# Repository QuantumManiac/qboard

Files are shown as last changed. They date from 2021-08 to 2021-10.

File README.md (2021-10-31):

# QBoard
A custom (almost) full-size mechanical keyboard with a detachable numpad

## Pictures
Keyboard PCB
Keyboard Picture

## BOM
A BOM of parts used can be found [here](https://github.com/QuantumManiac/qboard/tree/main/bom)

## Firmware
Rough notes for configuring the MCU and flashing firmware can be found [here](https://github.com/QuantumManiac/qboard/tree/main/qmk_firmware)

## Improvements
- Improving on the numpad connector - don't fit well and when connected isn't sturdy
- Switching out direct soldering of keyswitches onto PCB with hot-swap sockets

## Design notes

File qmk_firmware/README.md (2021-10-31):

# Firmware Notes
Below are some rough notes that I wrote as I was figuring out how to get the various configurations and USB bootloader onto the MCU with my Raspberry Pi.

[USBaspLoader and QMK on ATmega328P · GitHub](https://gist.github.com/nullstalgia/e5a010c50061e54cbc88b9ea4e2468e2)

## Connecting AVRDude on RasPi to ATMega

Instructions: [How to Program an AVR/Arduino using the Raspberry Pi GPIO](https://ozzmaker.com/program-avr-using-raspberry-pi-gpio/)

- When install avrdude, DO NOT IGNORE the warnings that `libusb`, `libftdi` not installed, need to install
- Note - this is for an arduino. Use this MCU's pinout and `-p` flag (for avrdude)
  - `-p` flag (use `-p m32`): [AVRDUDE: 2.1 Option Descriptions](https://www.nongnu.org/avrdude/user-manual/avrdude_4.html)
  - ATMega32 Datasheet: [ATmega32/L Datasheet](https://www.mouser.ca/datasheet/2/268/doc2503-1315184.pdf)
  - RasPi 3B Rev 1 pinout: [Pin Numbering - Raspberry Pi 3 Model B](https://pi4j.com/1.2/pins/model-3b-rev1.html)

## Setting Fuses

Fuse Calculator: [AVR® Fuse Calculator – The Engbedded Blog](https://www.engbedded.com/fusecalc/)

Fuse Flashing Instructions: [Mechanical Keyboard Prototype With V-USB & QMK](https://www.ghost7.com/mechanical-keyboard-prototype-with-v-usb-qmk/)

- Setting fuses to use external xtal and disable brownout protection
- Don't forget to hook up xtal as described (22pF caps w/ 16MHz xtal)
- Use ATMega32A settings for avrdude
  - `sudo avrdude -c linuxgpio -p m32 -v -u -U lfuse:w:0x1F:m -U hfuse:w:0xC0:m`

## Flashing USBaspLoader

See first section of: [USBaspLoader and QMK on ATmega328P · GitHub](https://gist.github.com/nullstalgia/e5a010c50061e54cbc88b9ea4e2468e2)

Also see relevant section of: [Mechanical Keyboard Prototype With V-USB & QMK](https://www.ghost7.com/mechanical-keyboard-prototype-with-v-usb-qmk/)

- In `Makefile.inc` for USBaspLoader, set gpio as programmer
  - `PROGRAMMER = -c linuxgpio`
- Make following changes to `bootloaderconfig.h`
  - `#define USB\_CFG\_INTPORT\_BIT 2`
  - `#define USB\_CFG\_DMINUS\_BIT 3`
  - `#define JUMPER\_BIT 6`

- Flash USBAspLoader

## Flash QMK

Guide on flashing the firmware: [QMK Firmware](https://docs.qmk.fm/#/hand_wire)

USB Driver Installer: [https://zadig.akeo.ie/](https://zadig.akeo.ie/)

- Short PD6 to GND (Or hold BOOT key) for programming mode when flashing firmware
- plug into PC w/ via USB
- May need to use to install libusbK if flashing doesn't work

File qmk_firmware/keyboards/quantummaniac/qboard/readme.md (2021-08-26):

# qboard

qboard

*A short description of the keyboard/project*

* Keyboard Maintainer: [QuantumManiac](https://github.com/QuantumManiac)
* Hardware Supported: *The PCBs, controllers supported*
* Hardware Availability: *Links to where you can find this hardware*

Make example for this keyboard (after setting up your build environment):

    make qboard:default

Flashing example for this keyboard:

    make qboard:default:flash

See the [build environment setup](https://docs.qmk.fm/#/getting_started_build_tools) and the [make instructions](https://docs.qmk.fm/#/getting_started_make_guide) for more information. Brand new to QMK? Start with our [Complete Newbs Guide](https://docs.qmk.fm/#/newbs).

## Bootloader

Enter the bootloader in 3 ways:

* **Bootmagic reset**: Hold down the key at (0,0) in the matrix (usually the top left key or Escape) and plug in the keyboard
* **Physical reset button**: Briefly press the button on the back of the PCB - some may have pads you must short instead
* **Keycode in layout**: Press the key mapped to `RESET` if it is available

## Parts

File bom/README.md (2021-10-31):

# Bill of Materials
|Name |Description |Qty|Link |Comments |
|---|---|---|---|---|
|CHERRY MX 3 PIN SWITCHES - BLUE |Keyswitches |101|[Link](https://kbdfans.com/collections/cherry-switches/products/cherry-mx-swtich?variant=36019543757) |Replace with 3-pin MX switches of choice |
|3mm LEDs - 2 Pin |Keyswitch and Indicator LEDs |105|[Link](https://www.amazon.ca/DiCUNO-1000pcs-Emitting-Diffused-Assorted/dp/B07KGQMGY7) |Pick color of choice. Ensure 3mm and preferably flange-less |
|ATMEGA32-16PU |Microcontroller |1  |[Link](https://www.mouser.ca/ProductDetail/Microchip-Technology-Atmel/ATMEGA32-16PU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) | |
|TZX3V6A-TR |Zener Diodes - 3.6V |2  |[Link](https://www.mouser.ca/ProductDetail/Vishay-Semiconductors/TZX3V6A-TR?qs=oNDV51lhjENtvfdCBFOJTw%3D%3D) |For USB-C |
|MF-R050 |Resettable Fuse - 500mA |1  |[Link](https://www.mouser.ca/ProductDetail/Bourns/MF-R050?qs=A6omU7D3gEWzJRzbTsuTwA%3D%3D) | |
|MJTP1230A |Pushbutton Switch |2  |[Link](https://www.mouser.ca/ProductDetail/Apem/MJTP1230A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) |For BOOT and RESET switches |
|ABL-16.000MHz-B4Y |Crystal - 16MHz |1  |[Link](https://www.mouser.ca/ProductDetail/ABRACON/ABL-16000MHz-B4Y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) |MCU Clock |
|1N4148TR |Diodes - Ultra-fast, 100V, 0.3A|102|[Link](https://www.mouser.ca/ProductDetail/onsemi-Fairchild/1N4148TR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) |Diodes for keys |
|10k R |Resistors |2  |[Link](https://www.mouser.ca/ProductDetail/YAGEO/MFR-12FRF52-10K?qs=19cKSROHwrBLAZVjkXsohw%3D%3D) | |
|1.5k R |Resistors |5  |[Link](https://www.mouser.ca/ProductDetail/YAGEO/MFR-12FTF52-1K5?qs=oAGoVhmvjhypP%2FVrWmgF1g%3D%3D) | |
|5.1k R |Resistors |2  |[Link](https://www.mouser.ca/ProductDetail/YAGEO/MFR-12FTF52-5K1?qs=oAGoVhmvjhy1wGcoKYGIuA%3D%3D) | |
|75 R |Resistors |2  |[Link](https://www.mouser.ca/ProductDetail/YAGEO/CFR-12JR-52-75R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) | |
|470 R |Resistors |102|[Link](https://www.mouser.ca/ProductDetail/YAGEO/CFR-12JT-52-470R?qs=sGAEpiMZZMtG0KNrPCHnjXb9qW87MP8uBQR6Le236lY%3D) | |
|22p C |Capacitors |2  |[Link](https://www.mouser.ca/ProductDetail/Murata-Electronics/RCE5C2A220J0A2H03B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) | |
|4.7u C (Polarized) |Capacitors |1  |[Link](https://www.mouser.ca/ProductDetail/Nichicon/UMT1H4R7MDD1TP?qs=Q7H%2Fb6Evq9zwCrKrvu5SEQ%3D%3D) | |
|0.1u C |Capacitors |2  |[Link](https://www.mouser.ca/ProductDetail/Murata-Electronics/RDER71H104K0M1H03A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) | |
|ORIGINAL CHERRY PCB-MOUNT STABILIZERS|Key Stabilizers |1  |[Link](https://kbdfans.com/products/cherry-original-pcb-stabilizers?variant=39444796997771) |Need 4x 2U, 2x 2.25U, 1x 6.25U |
|571-1-2199299-5 |IC Socket - 40-Pin |1  |[Link](https://www.digikey.ca/en/products/detail/te-connectivity-amp-connectors/1-2199299-5/5022052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) | |
|640-USB4085-GF-A |Through-hole USB-C Connector |1  |[Link](https://www.digikey.ca/en/products/detail/gct/USB4085-GF-A/9859662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) | |
|726-IPI45N06S409AKSA |MOSFET NPN Transistor |1  |[Link](https://www.digikey.ca/en/products/detail/IPP060N06NAKSA1/IPP060N06NAKSA1-ND/3687558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)|For LED Backlighting |
|SBH11-PBPC-D08-RA-BK |2x7 connector (Male) |1  |[Link](https://www.digikey.ca/en/products/detail/sullins-connector-solutions/SBH11-PBPC-D08-RA-BK/1990072) |For connecting numpad. The male and female connector DO NOT pair up well. Suggest finding alternative |
|PPPC082LJBN-RC |2x7 connector (Female) |1  |[Link](https://www.digikey.ca/en/products/detail/sullins-connector-solutions/PPPC082LJBN-RC/776019) |For connecting numpad. The male and female connector DO NOT pair up well. Suggest finding alternative |
|571-2842126-3 |3x2 Pin Header |1  |[Link](https://www.digikey.ca/en/products/detail/amphenol-icc-fci/10129381-906001BLF/7916070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) |ISP Header for programming the MCU |
|Adhesive-Back Bumpers - 95495K15 |Grippy Feet |8  |[Link](https://www.mcmaster.com/catalog/127/4126) |Feet for keyboard |
|611-PTS645VH392 |Horizontal Pushbutton Switch |1  |[Link](https://www.digikey.ca/en/products/detail/c-k/PTS645VH39-2-LFS/1146767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) |Switch for adjusting backlight |
|M2 Standoff Assorted Kit |Standoffs |1  |[Link](https://www.amazon.ca/Litorange-320PCS-Standoff-Assorted-Assortment/dp/B07D78PFQL) |Used 10mm between base plate and PCB. 15mm between PCB and clear cover. Use male-female on one standoff when going base plate -> PCB -> cover, else use female-female|
|M2 Screws |Screws |?  |N/A | |
|3mm Acrylic - Clear |Acrylic |1  |N/A |Use "_cover_acrylic_clear" file for cuts |
|3mm Acrylic - Black |Acrylic |1  |N/A |Use "_plate_acrylic_black" file for cuts |
|PCB - Black |PCBs |1  |[Link](https://jlcpcb.com/) |One of each "main" and "numpad" |

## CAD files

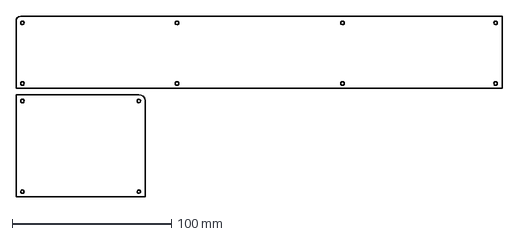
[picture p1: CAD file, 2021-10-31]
acrylic/_cover_acrylic_clear.dxf
304.8 x 112.9 mm

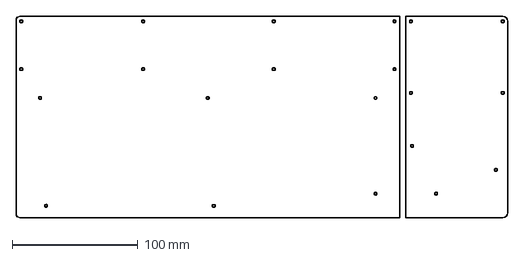
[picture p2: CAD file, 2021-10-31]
acrylic/_plate_acrylic_black.dxf
390.9 x 160.2 mm

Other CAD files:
acrylic/main_plate.dwg
acrylic/numpad_plate.dwg
acrylic/_cover_acrylic_clear.dwg
acrylic/_plate_acrylic_black.dwg

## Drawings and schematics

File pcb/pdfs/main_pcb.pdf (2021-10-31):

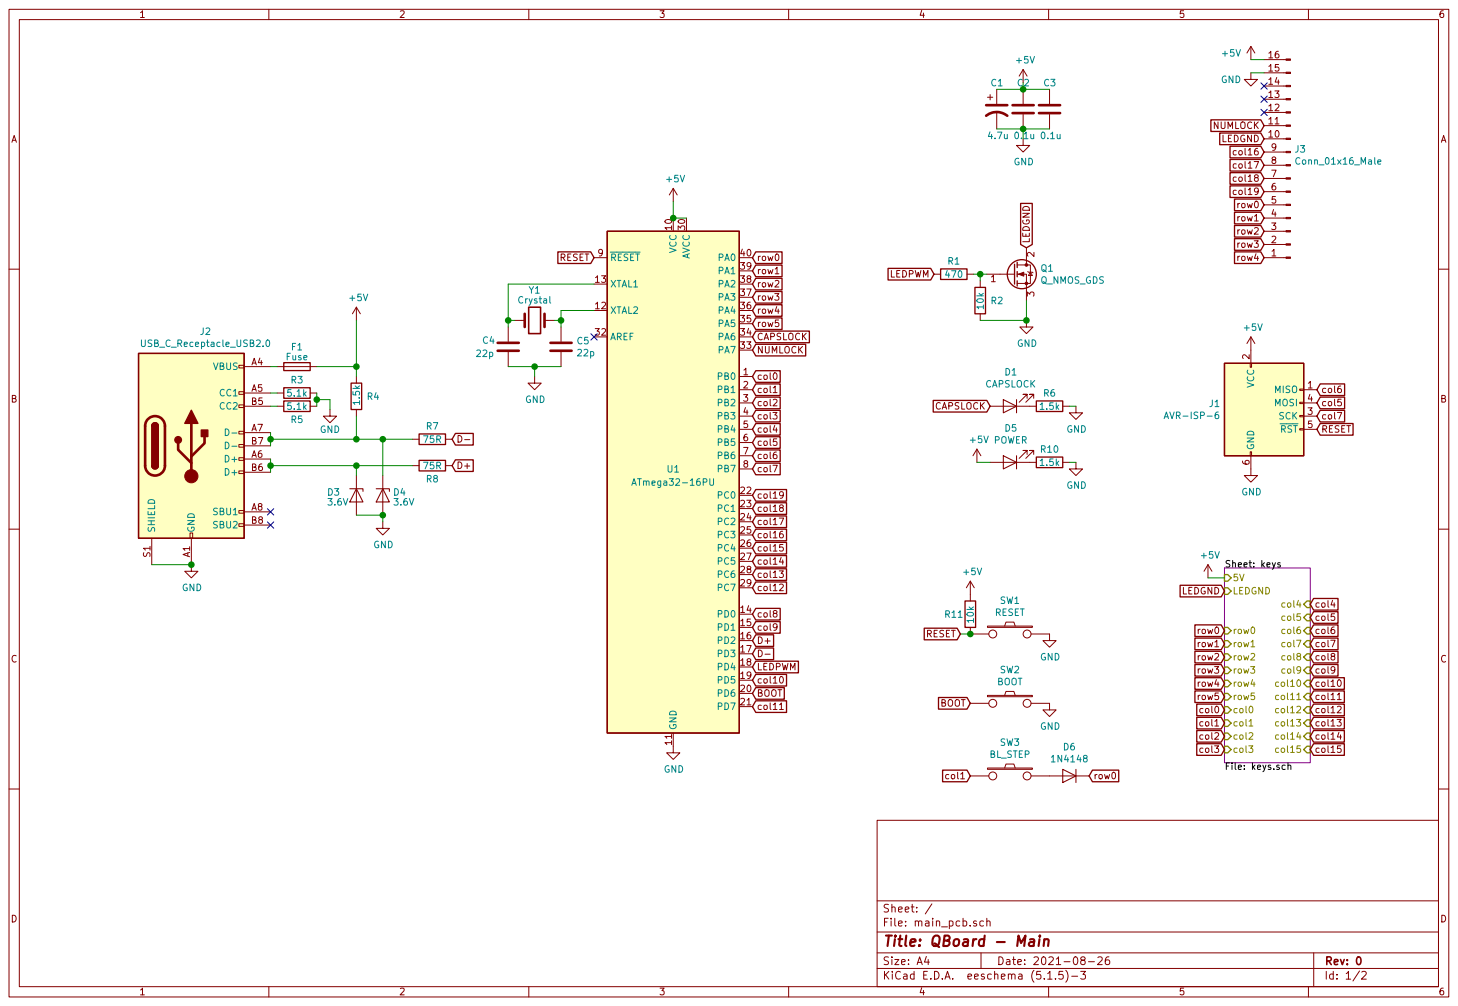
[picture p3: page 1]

Id: 1/2 Title: QBoard - Main

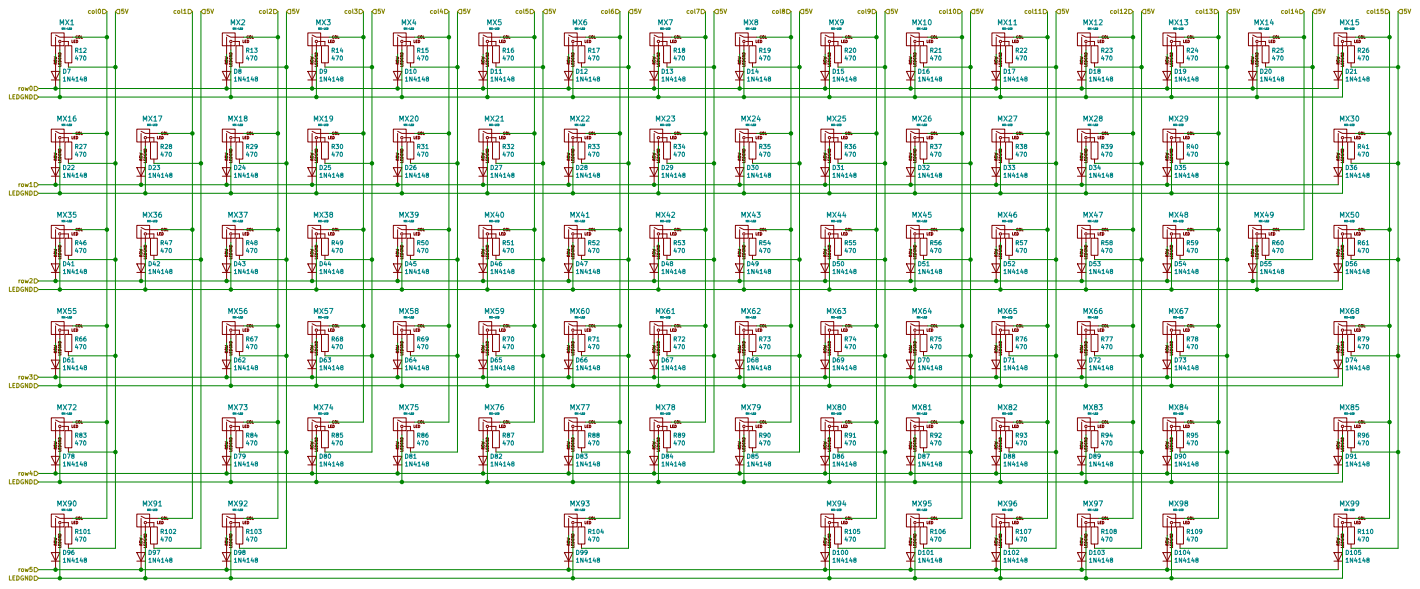
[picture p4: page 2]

Sheet: /keys/
File: keys.sch
Id: 2/2 Title: QBoard - Main Keys

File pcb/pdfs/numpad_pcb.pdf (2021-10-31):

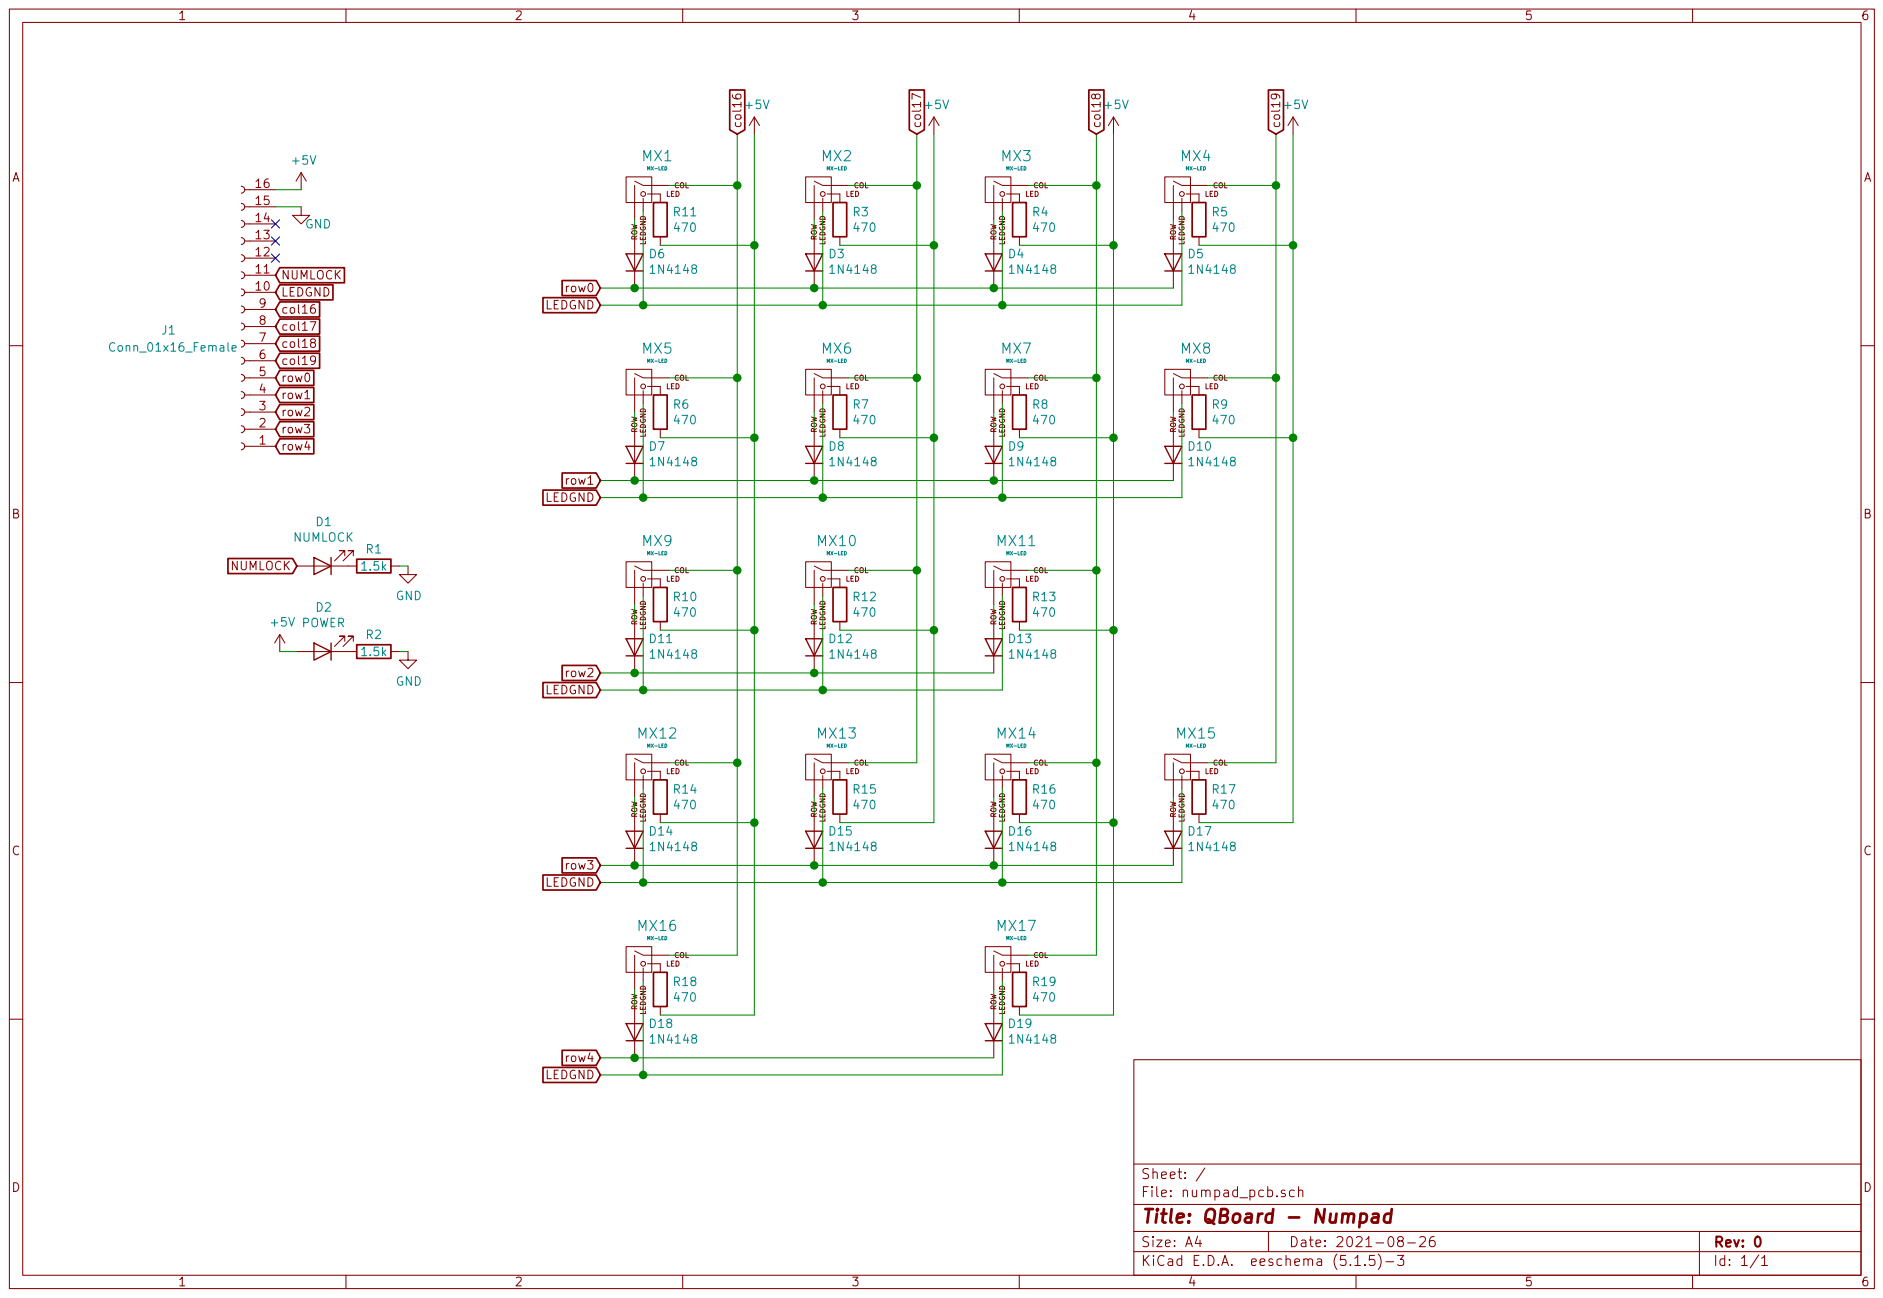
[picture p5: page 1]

File: numpad_pcb.sch Sheet: /
Id: 1/1 Title: QBoard - Numpad

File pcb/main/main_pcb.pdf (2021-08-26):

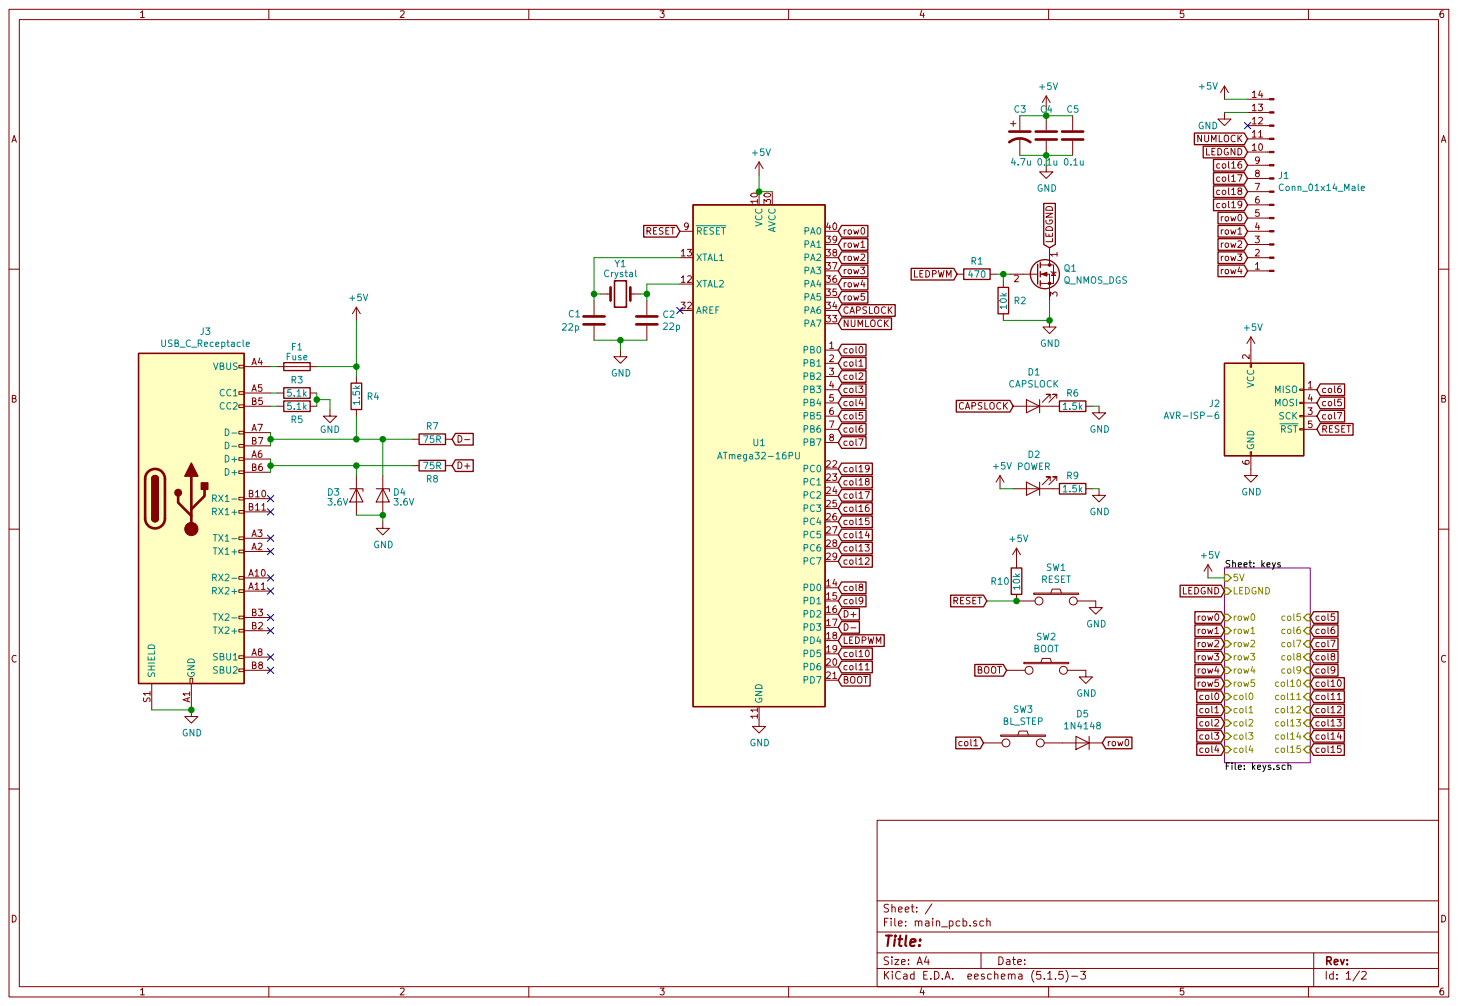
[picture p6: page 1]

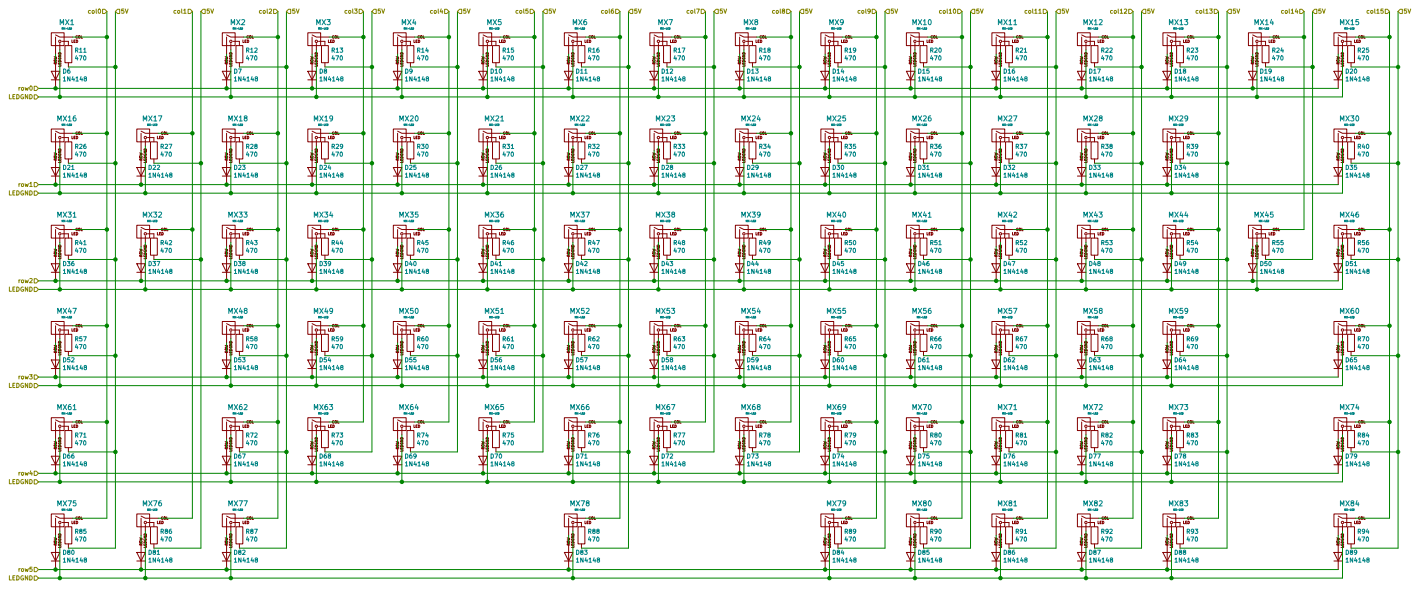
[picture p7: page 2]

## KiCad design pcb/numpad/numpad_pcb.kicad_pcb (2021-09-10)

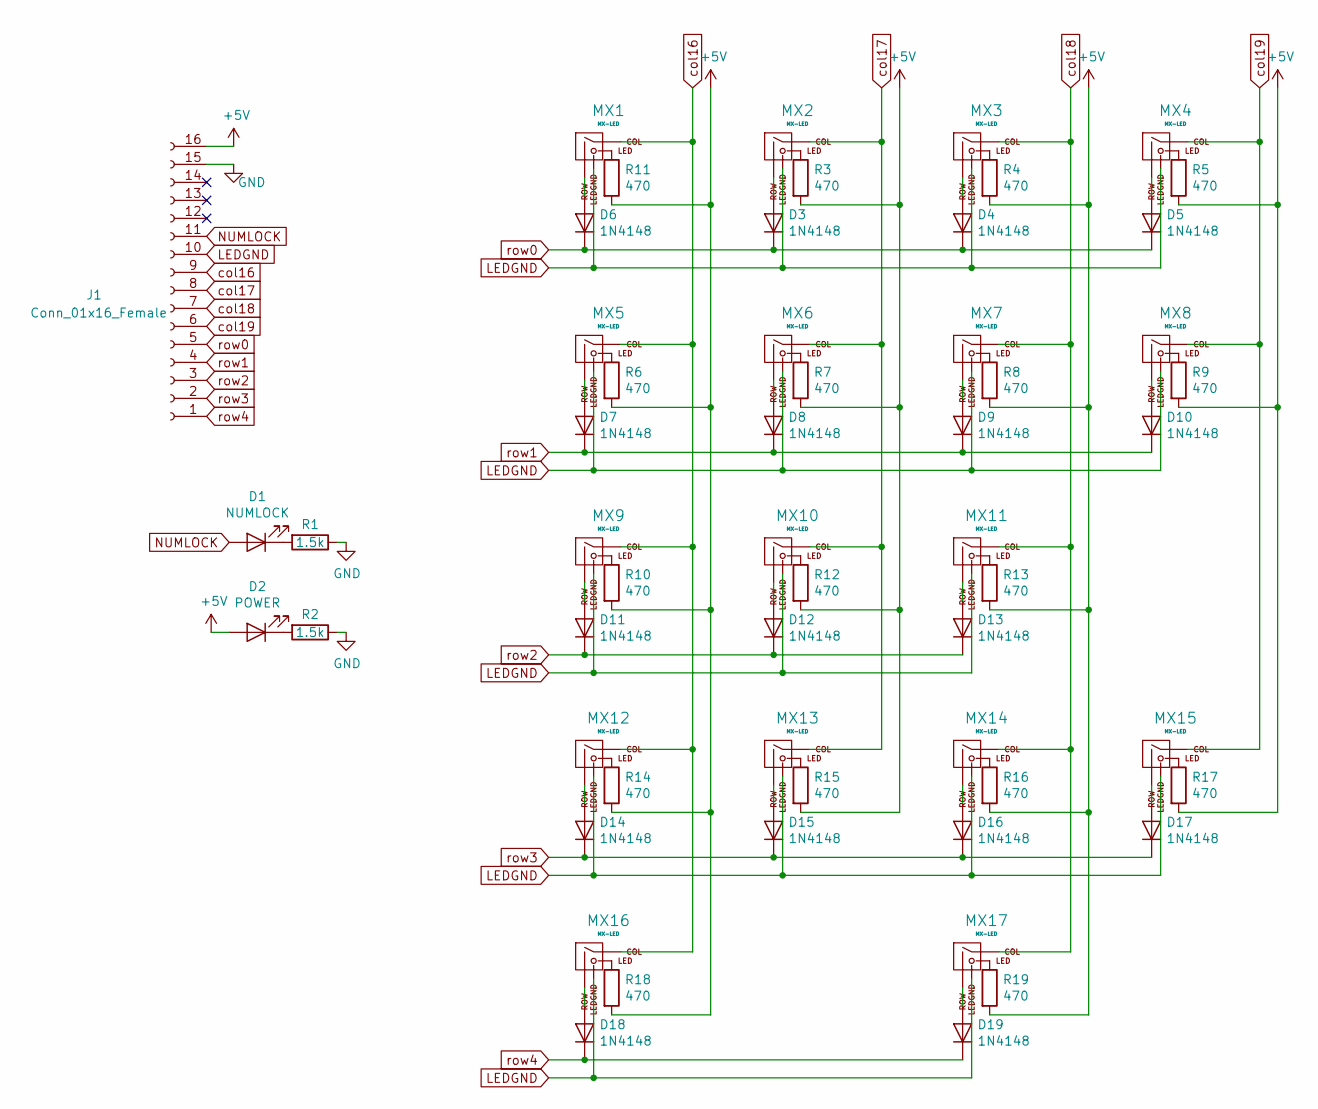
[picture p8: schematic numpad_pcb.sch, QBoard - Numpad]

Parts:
D1: NUMLOCK; LED_D3.0mm_Clear
D2: POWER; LED_D3.0mm_Clear
D3, D4, D5, D6, D7, D8, D9, D10, D11, D12, D13, D14, D15, D16, D17, D18, D19: 1N4148; D_DO-35_SOD27_P7.62mm_Horizontal
J1: Conn_01x16_Female; PinSocket_2x08_P2.54mm_Horizontal
MX1, MX2, MX3, MX4, MX5, MX6, MX7, MX9, MX10, MX11, MX12, MX13, MX14, MX17: MX-LED; MXOnly-1U
MX8, MX15: MX-LED; MXOnly-2U-ReversedVerticalStabilizers
MX16: MX-LED; MXOnly-2U-FLIPPED-ReversedStabilizers
R1, R2: 1.5k; R_Axial_DIN0204_L3.6mm_D1.6mm_P7.62mm_Horizontal
R3, R4, R5, R6, R7, R8, R9, R10, R11, R12, R13, R14, R15, R16, R17, R18, R19: 470; R_Axial_DIN0204_L3.6mm_D1.6mm_P7.62mm_Horizontal

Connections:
+5V: D2.2 (A), J1.16, R3.2, R4.2, R5.2, R6.2, R7.2, R8.2, R9.2, R10.2, R11.2, R12.2, R13.2, R14.2, R15.2, R16.2, R17.2, R18.2, R19.2
GND: J1.15, R1.1, R2.1
LEDGND: J1.10, MX1.4 (LEDGND), MX2.4 (LEDGND), MX3.4 (LEDGND), MX4.4 (LEDGND), MX5.4 (LEDGND), MX6.4 (LEDGND), MX7.4 (LEDGND), MX8.4 (LEDGND), MX9.4 (LEDGND), MX10.4 (LEDGND), MX11.4 (LEDGND), MX12.4 (LEDGND), MX13.4 (LEDGND), MX14.4 (LEDGND), MX15.4 (LEDGND), MX16.4 (LEDGND), MX17.4 (LEDGND)
NUMLOCK: D1.2 (A), J1.11
unnamed: D1.1 (K), R1.2
unnamed: D2.1 (K), R2.2
unnamed: D3.2 (A), MX2.2 (ROW)
unnamed: D4.2 (A), MX3.2 (ROW)
unnamed: D5.2 (A), MX4.2 (ROW)
unnamed: D6.2 (A), MX1.2 (ROW)
unnamed: D7.2 (A), MX5.2 (ROW)
unnamed: D8.2 (A), MX6.2 (ROW)
unnamed: D9.2 (A), MX7.2 (ROW)
unnamed: D10.2 (A), MX8.2 (ROW)
unnamed: D11.2 (A), MX9.2 (ROW)
unnamed: D12.2 (A), MX10.2 (ROW)
unnamed: D13.2 (A), MX11.2 (ROW)
unnamed: D14.2 (A), MX12.2 (ROW)
unnamed: D15.2 (A), MX13.2 (ROW)
unnamed: D16.2 (A), MX14.2 (ROW)
unnamed: D17.2 (A), MX15.2 (ROW)
unnamed: D18.2 (A), MX16.2 (ROW)
unnamed: D19.2 (A), MX17.2 (ROW)
unnamed: MX1.3 (LED), R11.1
unnamed: MX2.3 (LED), R3.1
unnamed: MX3.3 (LED), R4.1
unnamed: MX4.3 (LED), R5.1
unnamed: MX5.3 (LED), R6.1
unnamed: MX6.3 (LED), R7.1
unnamed: MX7.3 (LED), R8.1
unnamed: MX8.3 (LED), R9.1
unnamed: MX9.3 (LED), R10.1
unnamed: MX10.3 (LED), R12.1
unnamed: MX11.3 (LED), R13.1
unnamed: MX12.3 (LED), R14.1
unnamed: MX13.3 (LED), R15.1
unnamed: MX14.3 (LED), R16.1
unnamed: MX15.3 (LED), R17.1
unnamed: MX16.3 (LED), R18.1
unnamed: MX17.3 (LED), R19.1
col16: J1.9, MX1.1 (COL), MX5.1 (COL), MX9.1 (COL), MX12.1 (COL), MX16.1 (COL)
col17: J1.8, MX2.1 (COL), MX6.1 (COL), MX10.1 (COL), MX13.1 (COL)
col18: J1.7, MX3.1 (COL), MX7.1 (COL), MX11.1 (COL), MX14.1 (COL), MX17.1 (COL)
col19: J1.6, MX4.1 (COL), MX8.1 (COL), MX15.1 (COL)
row0: D3.1 (K), D4.1 (K), D5.1 (K), D6.1 (K), J1.5
row1: D7.1 (K), D8.1 (K), D9.1 (K), D10.1 (K), J1.4
row2: D11.1 (K), D12.1 (K), D13.1 (K), J1.3
row3: D14.1 (K), D15.1 (K), D16.1 (K), D17.1 (K), J1.2
row4: D18.1 (K), D19.1 (K), J1.1

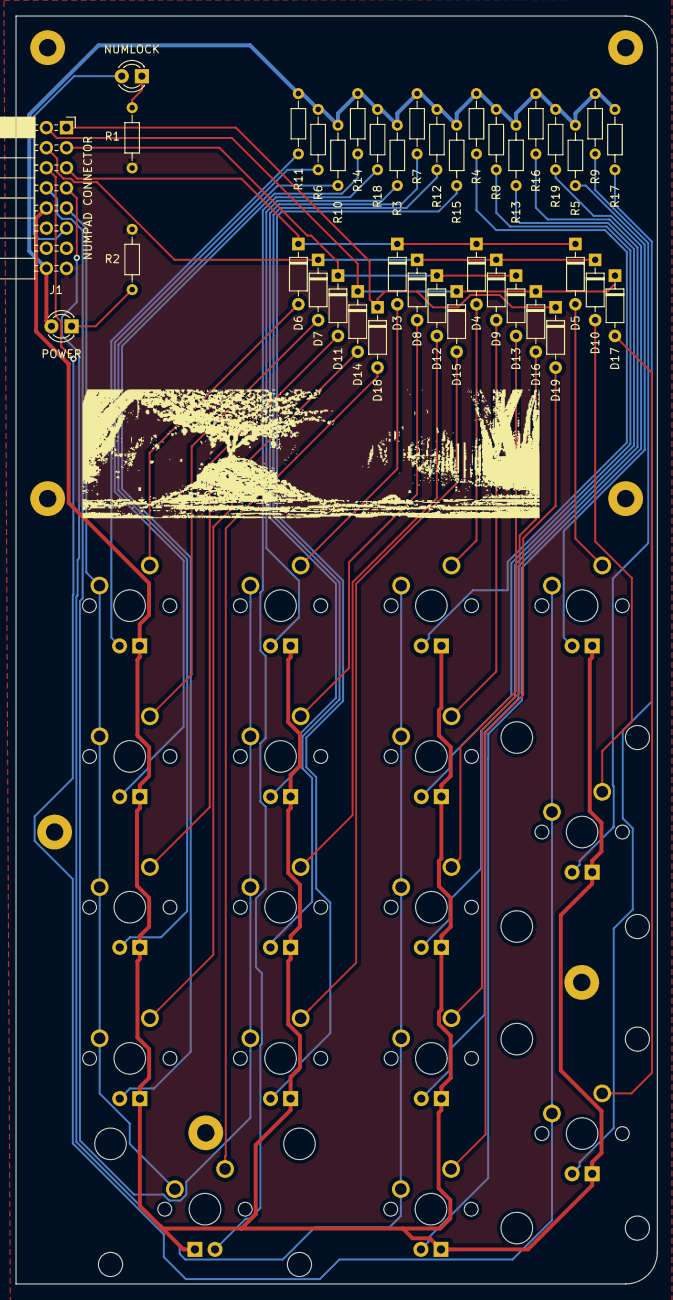
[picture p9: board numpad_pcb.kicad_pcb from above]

Board: 2 copper layers, 81.0 x 160.2 mm, 56 parts (0 on the bottom side), 49 nets.

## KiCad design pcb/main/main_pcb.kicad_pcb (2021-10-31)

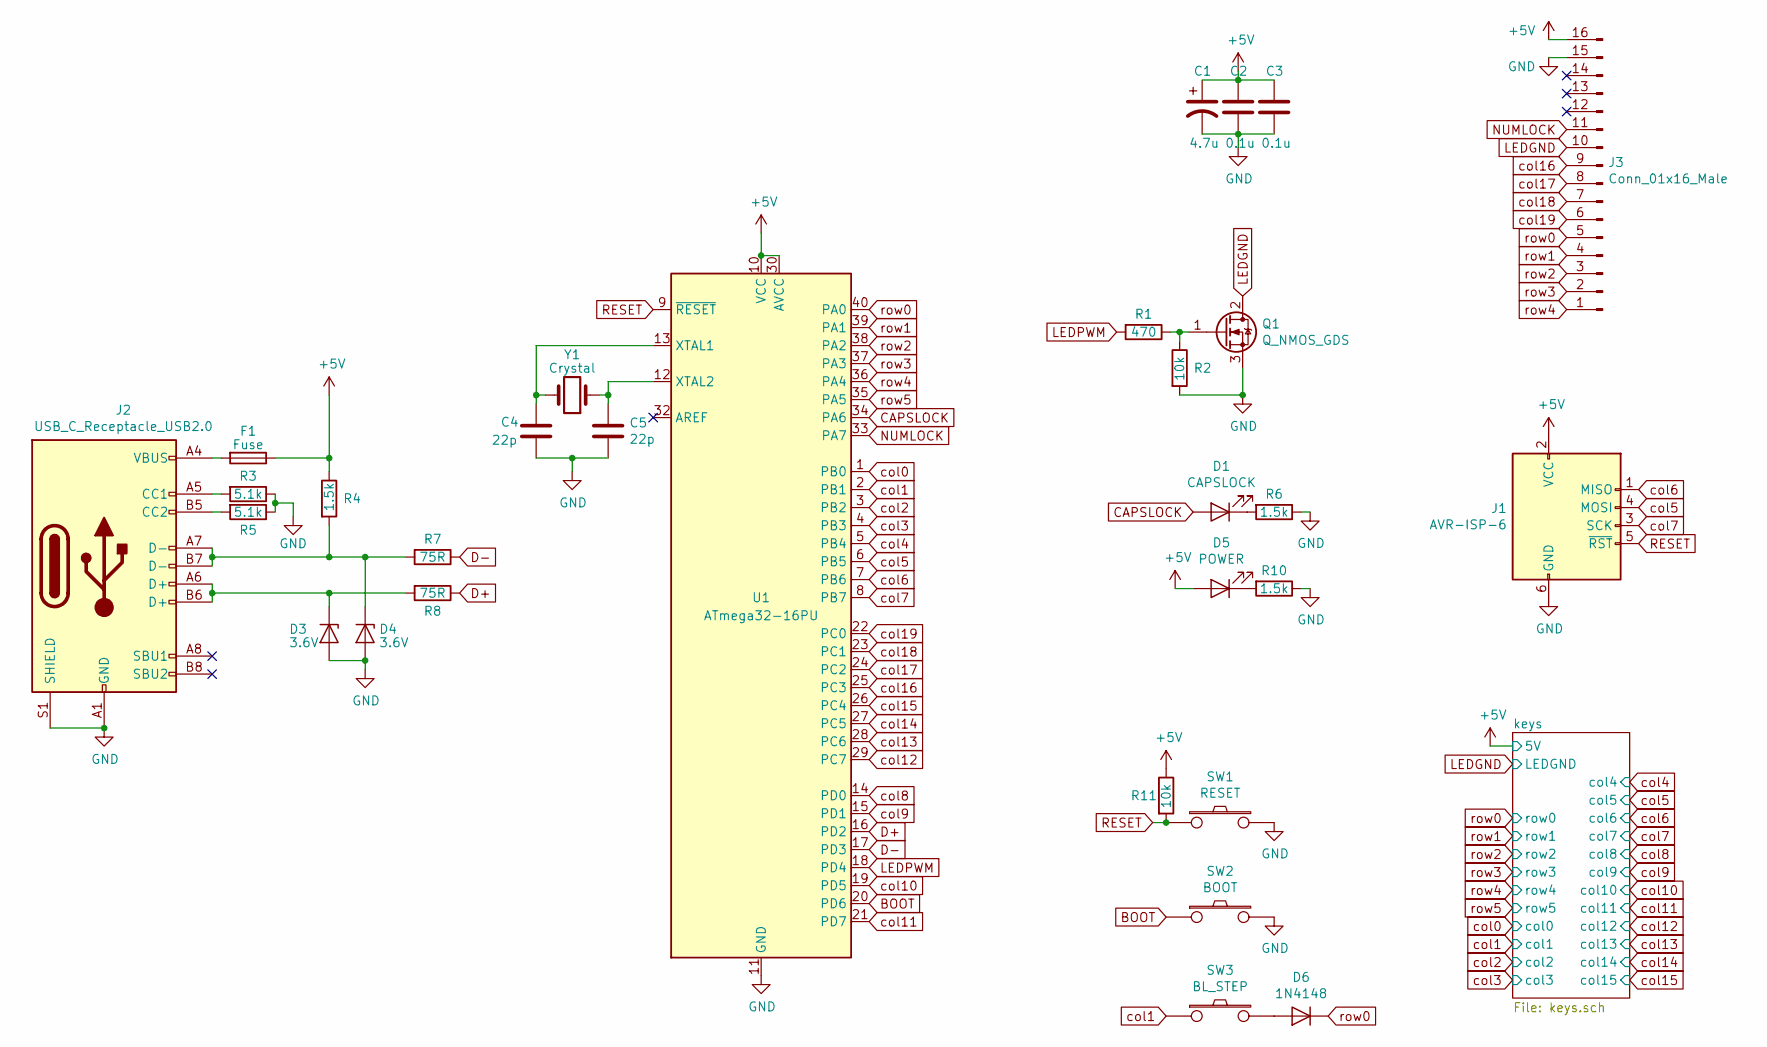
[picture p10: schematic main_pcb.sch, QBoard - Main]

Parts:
C1: 4.7u; CP_Radial_D4.0mm_P1.50mm
C2, C3: 0.1u; C_Disc_D4.3mm_W1.9mm_P5.00mm
C4, C5: 22p; C_Disc_D3.0mm_W1.6mm_P2.50mm
D1: CAPSLOCK; LED_D3.0mm_Clear
D3, D4: 3.6V; D_DO-35_SOD27_P7.62mm_Horizontal
D5: POWER; LED_D3.0mm_Clear
D6: 1N4148; D_DO-35_SOD27_P7.62mm_Horizontal
F1: Fuse; C_Disc_D5.0mm_W2.5mm_P5.00mm
J1: AVR-ISP-6; PinHeader_2x03_P2.54mm_Vertical
J2: USB_C_Receptacle_USB2.0; USB_C_Receptacle_GCT_USB4085
J3: Conn_01x16_Male; PinHeader_2x08_P2.54mm_Horizontal
Q1: Q_NMOS_GDS; TO-262-3_Vertical
R1: 470; R_Axial_DIN0204_L3.6mm_D1.6mm_P7.62mm_Horizontal
R2, R11: 10k; R_Axial_DIN0204_L3.6mm_D1.6mm_P7.62mm_Horizontal
R3, R5: 5.1k; R_Axial_DIN0204_L3.6mm_D1.6mm_P7.62mm_Horizontal
R4, R6, R10: 1.5k; R_Axial_DIN0204_L3.6mm_D1.6mm_P7.62mm_Horizontal
R7, R8: 75R; R_Axial_DIN0204_L3.6mm_D1.6mm_P7.62mm_Horizontal
SW1: RESET; SW_PUSH_6mm
SW2: BOOT; SW_PUSH_6mm
SW3: BL_STEP; SW_Tactile_SPST_Angled_PTS645Vx31-2LFS
U1: ATmega32-16PU; DIP-40_W15.24mm
Y1: Crystal; Crystal_HC49-4H_Vertical

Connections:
+5V: C1.1, C2.1, C3.1, D5.2 (A), F1.1, J1.2 (VCC), J3.16, R4.1, R11.1, U1.10 (VCC), U1.30 (AVCC); also elsewhere on the board
BOOT: SW2.1, U1.20 (PD6)
CAPSLOCK: D1.2 (A), U1.34 (PA6)
D+: R8.1, U1.16 (PD2)
D-: R7.1, U1.17 (PD3)
GND: C1.2, C2.2, C3.2, C4.2, C5.2, D3.2 (A), D4.2 (A), J1.6 (GND), J2.A1 (GND), J2.A12 (GND), J2.B1 (GND), J2.B12 (GND), J2.S1 (SHIELD), J3.15, Q1.3 (S), R2.2, R3.1, R5.1, R6.1, R10.1, SW1.2, SW2.2, U1.11 (GND), U1.31 (GND)
LEDGND: J3.10, Q1.2 (D); also elsewhere on the board
LEDPWM: R1.2, U1.18 (PD4)
NUMLOCK: J3.11, U1.33 (PA7)
unnamed: C4.1, U1.13 (XTAL1), Y1.2
unnamed: C5.1, U1.12 (XTAL2), Y1.1
unnamed: D1.1 (K), R6.2
unnamed: D3.1 (K), J2.A6 (D+), J2.B6 (D+), R8.2
unnamed: D4.1 (K), J2.A7 (D-), J2.B7 (D-), R4.2, R7.2
unnamed: D5.1 (K), R10.2
unnamed: D6.2 (A), SW3.2
unnamed: F1.2, J2.A4 (VBUS), J2.A9 (VBUS), J2.B4 (VBUS), J2.B9 (VBUS)
unnamed: J2.A5 (CC1), R3.2
unnamed: J2.B5 (CC2), R5.2
unnamed: Q1.1 (G), R1.1, R2.1
RESET: J1.5 (~RST), R11.2, SW1.1, U1.9 (~RESET)
col0: U1.1 (PB0); also elsewhere on the board
col1: SW3.1, U1.2 (PB1); also elsewhere on the board
col2: U1.3 (PB2); also elsewhere on the board
col3: U1.4 (PB3); also elsewhere on the board
col4: U1.5 (PB4); also elsewhere on the board
col5: J1.4 (MOSI), U1.6 (PB5); also elsewhere on the board
col6: J1.1 (MISO), U1.7 (PB6); also elsewhere on the board
col7: J1.3 (SCK), U1.8 (PB7); also elsewhere on the board
col8: U1.14 (PD0); also elsewhere on the board
col9: U1.15 (PD1); also elsewhere on the board
col10: U1.19 (PD5); also elsewhere on the board
col11: U1.21 (PD7); also elsewhere on the board
col12: U1.29 (PC7); also elsewhere on the board
col13: U1.28 (PC6); also elsewhere on the board
col14: U1.27 (PC5); also elsewhere on the board
col15: U1.26 (PC4); also elsewhere on the board
col16: J3.9, U1.25 (PC3)
col17: J3.8, U1.24 (PC2)
col18: J3.7, U1.23 (PC1)
col19: J3.6, U1.22 (PC0)
row0: D6.1 (K), J3.5, U1.40 (PA0); also elsewhere on the board
row1: J3.4, U1.39 (PA1); also elsewhere on the board
row2: J3.3, U1.38 (PA2); also elsewhere on the board
row3: J3.2, U1.37 (PA3); also elsewhere on the board
row4: J3.1, U1.36 (PA4); also elsewhere on the board
row5: U1.35 (PA5); also elsewhere on the board

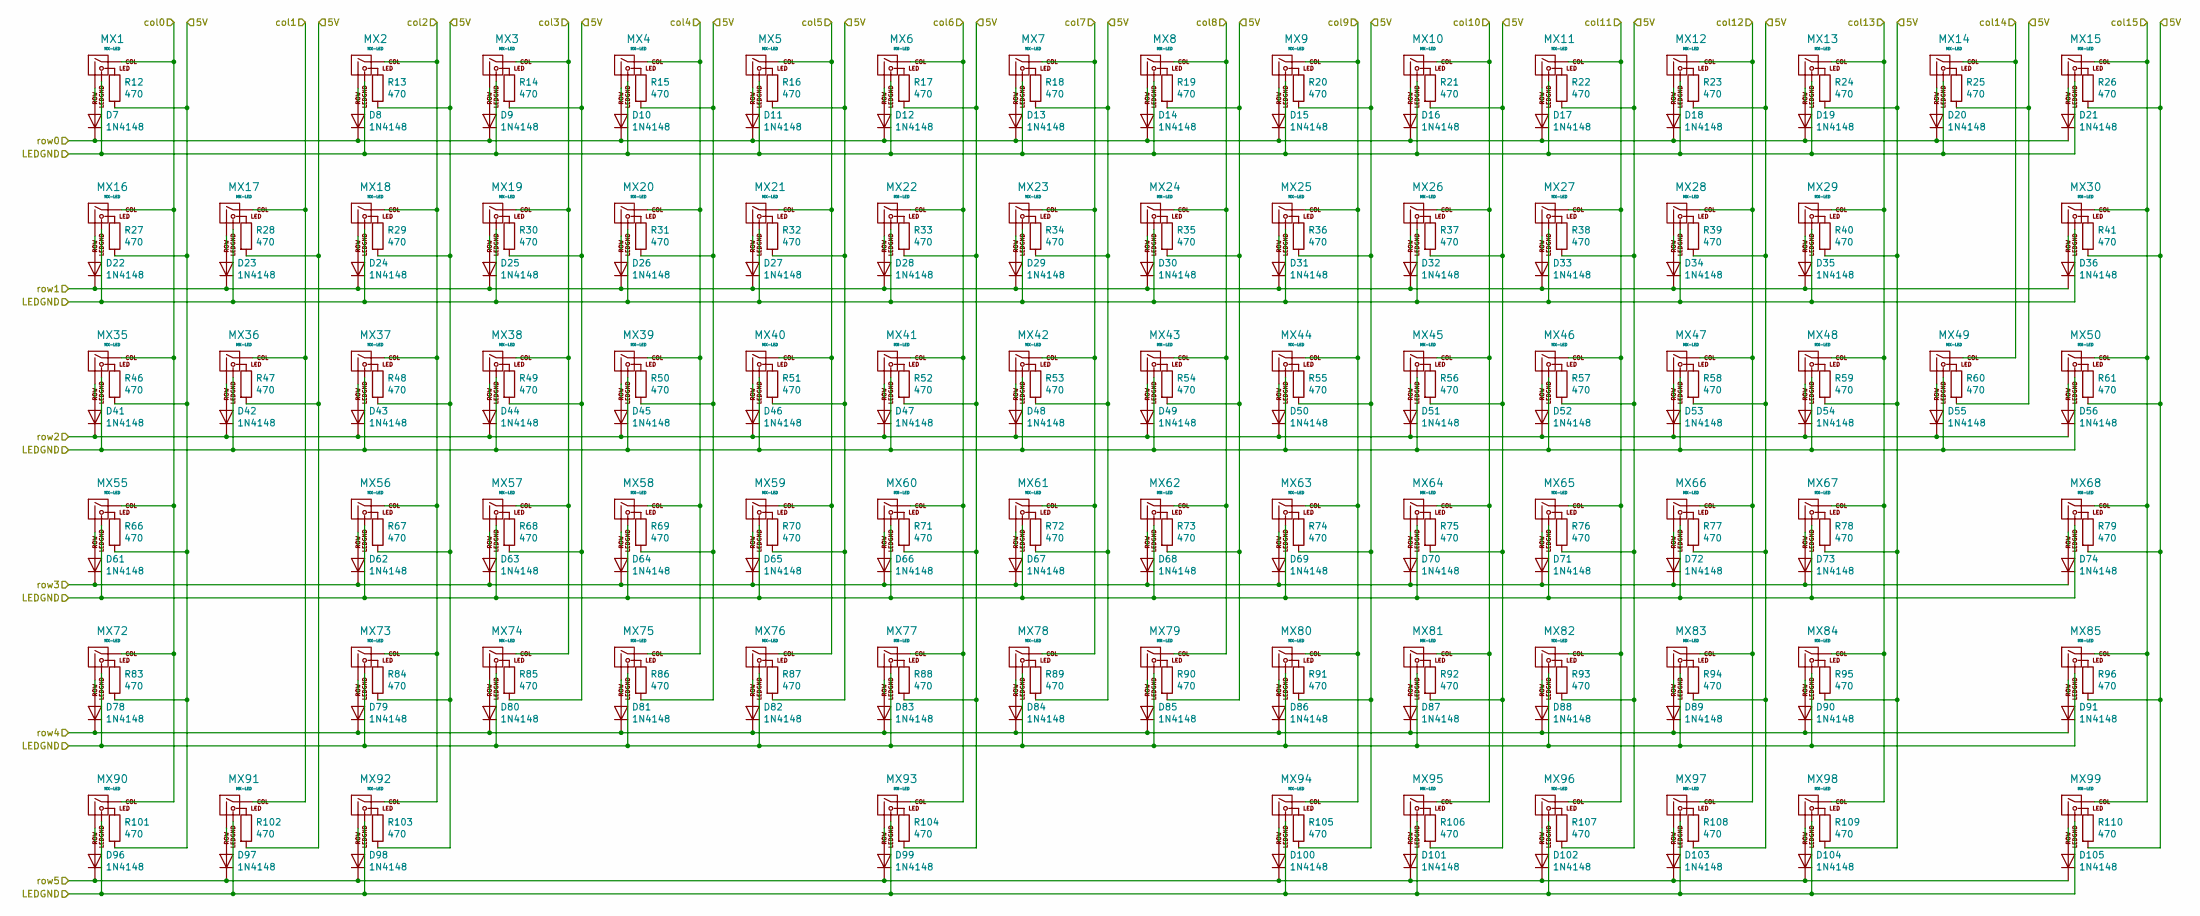
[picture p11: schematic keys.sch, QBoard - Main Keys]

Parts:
D7, D8, D9, D10, D11, D12, D13, D14, D15, D16, D17, D18, D19, D20, D21, D22, D23, D24, D25, D26, D27, D28, D29, D30, D31, D32, D33, D34, D35, D36, D41, D42, D43, D44, D45, D46, D47, D48, D49, D50, D51, D52, D53, D54, D55, D56, D61, D62, D63, D64, D65, D66, D67, D68, D69, D70, D71, D72, D73, D74, D78, D79, D80, D81, D82, D83, D84, D85, D86, D87, D88, D89, D90, D91, D96, D97, D98, D99, D100, D101, D102, D103, D104, D105: 1N4148; D_DO-35_SOD27_P7.62mm_Horizontal
MX1, MX2, MX3, MX4, MX5, MX6, MX7, MX8, MX9, MX10, MX11, MX12, MX13, MX14, MX15, MX16, MX17, MX18, MX19, MX20, MX21, MX22, MX23, MX24, MX25, MX26, MX27, MX28, MX30, MX36, MX37, MX38, MX39, MX40, MX41, MX42, MX43, MX44, MX45, MX46, MX47, MX48, MX50, MX56, MX57, MX58, MX59, MX60, MX61, MX62, MX63, MX64, MX65, MX66, MX68, MX73, MX74, MX75, MX76, MX77, MX78, MX79, MX80, MX81, MX82, MX84, MX85, MX94, MX95, MX96, MX97, MX98, MX99: MX-LED; MXOnly-1U
MX29: MX-LED; MXOnly-2U
MX35, MX49: MX-LED; MXOnly-1.5U
MX55, MX83: MX-LED; MXOnly-1.75U
MX67: MX-LED; MXOnly-2.25U-FLIPPED
MX72: MX-LED; MXOnly-2.25U
MX90, MX91, MX92: MX-LED; MXOnly-1.25U
MX93: MX-LED; MXOnly-6.25U-ReversedStabilizers
R12, R13, R14, R15, R16, R17, R18, R19, R20, R21, R22, R23, R24, R25, R26, R27, R28, R29, R30, R31, R32, R33, R34, R35, R36, R37, R38, R39, R40, R41, R46, R47, R48, R49, R50, R51, R52, R53, R54, R55, R56, R57, R58, R59, R60, R61, R66, R67, R68, R69, R70, R71, R72, R73, R74, R75, R76, R77, R78, R79, R83, R84, R85, R86, R87, R88, R89, R90, R91, R92, R93, R94, R95, R96, R101, R102, R103, R104, R105, R106, R107, R108, R109, R110: 470; R_Axial_DIN0204_L3.6mm_D1.6mm_P7.62mm_Horizontal

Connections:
+5V: R12.2, R13.2, R14.2, R15.2, R16.2, R17.2, R18.2, R19.2, R20.2, R21.2, R22.2, R23.2, R24.2, R25.2, R26.2, R27.2, R28.2, R29.2, R30.2, R31.2, R32.2, R33.2, R34.2, R35.2, R36.2, R37.2, R38.2, R39.2, R40.2, R41.2, R46.2, R47.2, R48.2, R49.2, R50.2, R51.2, R52.2, R53.2, R54.2, R55.2, R56.2, R57.2, R58.2, R59.2, R60.2, R61.2, R66.2, R67.2, R68.2, R69.2, R70.2, R71.2, R72.2, R73.2, R74.2, R75.2, R76.2, R77.2, R78.2, R79.2, R83.2, R84.2, R85.2, R86.2, R87.2, R88.2, R89.2, R90.2, R91.2, R92.2, R93.2, R94.2, R95.2, R96.2, R101.2, R102.2, R103.2, R104.2, R105.2, R106.2, R107.2, R108.2, R109.2, R110.2; also elsewhere on the board
LEDGND: MX1.4 (LEDGND), MX2.4 (LEDGND), MX3.4 (LEDGND), MX4.4 (LEDGND), MX5.4 (LEDGND), MX6.4 (LEDGND), MX7.4 (LEDGND), MX8.4 (LEDGND), MX9.4 (LEDGND), MX10.4 (LEDGND), MX11.4 (LEDGND), MX12.4 (LEDGND), MX13.4 (LEDGND), MX14.4 (LEDGND), MX15.4 (LEDGND), MX16.4 (LEDGND), MX17.4 (LEDGND), MX18.4 (LEDGND), MX19.4 (LEDGND), MX20.4 (LEDGND), MX21.4 (LEDGND), MX22.4 (LEDGND), MX23.4 (LEDGND), MX24.4 (LEDGND), MX25.4 (LEDGND), MX26.4 (LEDGND), MX27.4 (LEDGND), MX28.4 (LEDGND), MX29.4 (LEDGND), MX30.4 (LEDGND), MX35.4 (LEDGND), MX36.4 (LEDGND), MX37.4 (LEDGND), MX38.4 (LEDGND), MX39.4 (LEDGND), MX40.4 (LEDGND), MX41.4 (LEDGND), MX42.4 (LEDGND), MX43.4 (LEDGND), MX44.4 (LEDGND), MX45.4 (LEDGND), MX46.4 (LEDGND), MX47.4 (LEDGND), MX48.4 (LEDGND), MX49.4 (LEDGND), MX50.4 (LEDGND), MX55.4 (LEDGND), MX56.4 (LEDGND), MX57.4 (LEDGND), MX58.4 (LEDGND), MX59.4 (LEDGND), MX60.4 (LEDGND), MX61.4 (LEDGND), MX62.4 (LEDGND), MX63.4 (LEDGND), MX64.4 (LEDGND), MX65.4 (LEDGND), MX66.4 (LEDGND), MX67.4 (LEDGND), MX68.4 (LEDGND), MX72.4 (LEDGND), MX73.4 (LEDGND), MX74.4 (LEDGND), MX75.4 (LEDGND), MX76.4 (LEDGND), MX77.4 (LEDGND), MX78.4 (LEDGND), MX79.4 (LEDGND), MX80.4 (LEDGND), MX81.4 (LEDGND), MX82.4 (LEDGND), MX83.4 (LEDGND), MX84.4 (LEDGND), MX85.4 (LEDGND), MX90.4 (LEDGND), MX91.4 (LEDGND), MX92.4 (LEDGND), MX93.4 (LEDGND), MX94.4 (LEDGND), MX95.4 (LEDGND), MX96.4 (LEDGND), MX97.4 (LEDGND), MX98.4 (LEDGND), MX99.4 (LEDGND); also elsewhere on the board
unnamed: D7.2 (A), MX1.2 (ROW)
unnamed: D8.2 (A), MX2.2 (ROW)
unnamed: D9.2 (A), MX3.2 (ROW)
unnamed: D10.2 (A), MX4.2 (ROW)
unnamed: D11.2 (A), MX5.2 (ROW)
unnamed: D12.2 (A), MX6.2 (ROW)
unnamed: D13.2 (A), MX7.2 (ROW)
unnamed: D14.2 (A), MX8.2 (ROW)
unnamed: D15.2 (A), MX9.2 (ROW)
unnamed: D16.2 (A), MX10.2 (ROW)
unnamed: D17.2 (A), MX11.2 (ROW)
unnamed: D18.2 (A), MX12.2 (ROW)
unnamed: D19.2 (A), MX13.2 (ROW)
unnamed: D20.2 (A), MX14.2 (ROW)
unnamed: D21.2 (A), MX15.2 (ROW)
unnamed: D22.2 (A), MX16.2 (ROW)
unnamed: D23.2 (A), MX17.2 (ROW)
unnamed: D24.2 (A), MX18.2 (ROW)
unnamed: D25.2 (A), MX19.2 (ROW)
unnamed: D26.2 (A), MX20.2 (ROW)
unnamed: D27.2 (A), MX21.2 (ROW)
unnamed: D28.2 (A), MX22.2 (ROW)
unnamed: D29.2 (A), MX23.2 (ROW)
unnamed: D30.2 (A), MX24.2 (ROW)
unnamed: D31.2 (A), MX25.2 (ROW)
unnamed: D32.2 (A), MX26.2 (ROW)
unnamed: D33.2 (A), MX27.2 (ROW)
unnamed: D34.2 (A), MX28.2 (ROW)
unnamed: D35.2 (A), MX29.2 (ROW)
unnamed: D36.2 (A), MX30.2 (ROW)
unnamed: D41.2 (A), MX35.2 (ROW)
unnamed: D42.2 (A), MX36.2 (ROW)
unnamed: D43.2 (A), MX37.2 (ROW)
unnamed: D44.2 (A), MX38.2 (ROW)
unnamed: D45.2 (A), MX39.2 (ROW)
unnamed: D46.2 (A), MX40.2 (ROW)
unnamed: D47.2 (A), MX41.2 (ROW)
unnamed: D48.2 (A), MX42.2 (ROW)
unnamed: D49.2 (A), MX43.2 (ROW)
unnamed: D50.2 (A), MX44.2 (ROW)
unnamed: D51.2 (A), MX45.2 (ROW)
unnamed: D52.2 (A), MX46.2 (ROW)
unnamed: D53.2 (A), MX47.2 (ROW)
unnamed: D54.2 (A), MX48.2 (ROW)
unnamed: D55.2 (A), MX49.2 (ROW)
unnamed: D56.2 (A), MX50.2 (ROW)
unnamed: D61.2 (A), MX55.2 (ROW)
unnamed: D62.2 (A), MX56.2 (ROW)
unnamed: D63.2 (A), MX57.2 (ROW)
unnamed: D64.2 (A), MX58.2 (ROW)
unnamed: D65.2 (A), MX59.2 (ROW)
unnamed: D66.2 (A), MX60.2 (ROW)
unnamed: D67.2 (A), MX61.2 (ROW)
unnamed: D68.2 (A), MX62.2 (ROW)
unnamed: D69.2 (A), MX63.2 (ROW)
unnamed: D70.2 (A), MX64.2 (ROW)
unnamed: D71.2 (A), MX65.2 (ROW)
unnamed: D72.2 (A), MX66.2 (ROW)
unnamed: D73.2 (A), MX67.2 (ROW)
unnamed: D74.2 (A), MX68.2 (ROW)
unnamed: D78.2 (A), MX72.2 (ROW)
unnamed: D79.2 (A), MX73.2 (ROW)
unnamed: D80.2 (A), MX74.2 (ROW)
unnamed: D81.2 (A), MX75.2 (ROW)
unnamed: D82.2 (A), MX76.2 (ROW)
unnamed: D83.2 (A), MX77.2 (ROW)
unnamed: D84.2 (A), MX78.2 (ROW)
unnamed: D85.2 (A), MX79.2 (ROW)
unnamed: D86.2 (A), MX80.2 (ROW)
unnamed: D87.2 (A), MX81.2 (ROW)
unnamed: D88.2 (A), MX82.2 (ROW)
unnamed: D89.2 (A), MX83.2 (ROW)
unnamed: D90.2 (A), MX84.2 (ROW)
unnamed: D91.2 (A), MX85.2 (ROW)
unnamed: D96.2 (A), MX90.2 (ROW)
unnamed: D97.2 (A), MX91.2 (ROW)
unnamed: D98.2 (A), MX92.2 (ROW)
unnamed: D99.2 (A), MX93.2 (ROW)
unnamed: D100.2 (A), MX94.2 (ROW)
unnamed: D101.2 (A), MX95.2 (ROW)
unnamed: D102.2 (A), MX96.2 (ROW)
unnamed: D103.2 (A), MX97.2 (ROW)
unnamed: D104.2 (A), MX98.2 (ROW)
unnamed: D105.2 (A), MX99.2 (ROW)
unnamed: MX1.3 (LED), R12.1
unnamed: MX2.3 (LED), R13.1
unnamed: MX3.3 (LED), R14.1
unnamed: MX4.3 (LED), R15.1
unnamed: MX5.3 (LED), R16.1
unnamed: MX6.3 (LED), R17.1
unnamed: MX7.3 (LED), R18.1
unnamed: MX8.3 (LED), R19.1
unnamed: MX9.3 (LED), R20.1
unnamed: MX10.3 (LED), R21.1
unnamed: MX11.3 (LED), R22.1
unnamed: MX12.3 (LED), R23.1
unnamed: MX13.3 (LED), R24.1
unnamed: MX14.3 (LED), R25.1
unnamed: MX15.3 (LED), R26.1
unnamed: MX16.3 (LED), R27.1
unnamed: MX17.3 (LED), R28.1
unnamed: MX18.3 (LED), R29.1
unnamed: MX19.3 (LED), R30.1
unnamed: MX20.3 (LED), R31.1
unnamed: MX21.3 (LED), R32.1
unnamed: MX22.3 (LED), R33.1
unnamed: MX23.3 (LED), R34.1
unnamed: MX24.3 (LED), R35.1
unnamed: MX25.3 (LED), R36.1
unnamed: MX26.3 (LED), R37.1
unnamed: MX27.3 (LED), R38.1
unnamed: MX28.3 (LED), R39.1
unnamed: MX29.3 (LED), R40.1
unnamed: MX30.3 (LED), R41.1
unnamed: MX35.3 (LED), R46.1
unnamed: MX36.3 (LED), R47.1
unnamed: MX37.3 (LED), R48.1
unnamed: MX38.3 (LED), R49.1
unnamed: MX39.3 (LED), R50.1
unnamed: MX40.3 (LED), R51.1
unnamed: MX41.3 (LED), R52.1
unnamed: MX42.3 (LED), R53.1
unnamed: MX43.3 (LED), R54.1
unnamed: MX44.3 (LED), R55.1
unnamed: MX45.3 (LED), R56.1
unnamed: MX46.3 (LED), R57.1
unnamed: MX47.3 (LED), R58.1
unnamed: MX48.3 (LED), R59.1
unnamed: MX49.3 (LED), R60.1
unnamed: MX50.3 (LED), R61.1
unnamed: MX55.3 (LED), R66.1
unnamed: MX56.3 (LED), R67.1
unnamed: MX57.3 (LED), R68.1
unnamed: MX58.3 (LED), R69.1
unnamed: MX59.3 (LED), R70.1
unnamed: MX60.3 (LED), R71.1
unnamed: MX61.3 (LED), R72.1
unnamed: MX62.3 (LED), R73.1
unnamed: MX63.3 (LED), R74.1
unnamed: MX64.3 (LED), R75.1
unnamed: MX65.3 (LED), R76.1
unnamed: MX66.3 (LED), R77.1
unnamed: MX67.3 (LED), R78.1
unnamed: MX68.3 (LED), R79.1
unnamed: MX72.3 (LED), R83.1
unnamed: MX73.3 (LED), R84.1
unnamed: MX74.3 (LED), R85.1
unnamed: MX75.3 (LED), R86.1
unnamed: MX76.3 (LED), R87.1
unnamed: MX77.3 (LED), R88.1
unnamed: MX78.3 (LED), R89.1
unnamed: MX79.3 (LED), R90.1
unnamed: MX80.3 (LED), R91.1
unnamed: MX81.3 (LED), R92.1
unnamed: MX82.3 (LED), R93.1
unnamed: MX83.3 (LED), R94.1
unnamed: MX84.3 (LED), R95.1
unnamed: MX85.3 (LED), R96.1
unnamed: MX90.3 (LED), R101.1
unnamed: MX91.3 (LED), R102.1
unnamed: MX92.3 (LED), R103.1
unnamed: MX93.3 (LED), R104.1
unnamed: MX94.3 (LED), R105.1
unnamed: MX95.3 (LED), R106.1
unnamed: MX96.3 (LED), R107.1
unnamed: MX97.3 (LED), R108.1
unnamed: MX98.3 (LED), R109.1
unnamed: MX99.3 (LED), R110.1
col0: MX1.1 (COL), MX16.1 (COL), MX35.1 (COL), MX55.1 (COL), MX72.1 (COL), MX90.1 (COL); also elsewhere on the board
col1: MX17.1 (COL), MX36.1 (COL), MX91.1 (COL); also elsewhere on the board
col2: MX2.1 (COL), MX18.1 (COL), MX37.1 (COL), MX56.1 (COL), MX73.1 (COL), MX92.1 (COL); also elsewhere on the board
col3: MX3.1 (COL), MX19.1 (COL), MX38.1 (COL), MX57.1 (COL), MX74.1 (COL); also elsewhere on the board
col4: MX4.1 (COL), MX20.1 (COL), MX39.1 (COL), MX58.1 (COL), MX75.1 (COL); also elsewhere on the board
col5: MX5.1 (COL), MX21.1 (COL), MX40.1 (COL), MX59.1 (COL), MX76.1 (COL); also elsewhere on the board
col6: MX6.1 (COL), MX22.1 (COL), MX41.1 (COL), MX60.1 (COL), MX77.1 (COL), MX93.1 (COL); also elsewhere on the board
col7: MX7.1 (COL), MX23.1 (COL), MX42.1 (COL), MX61.1 (COL), MX78.1 (COL); also elsewhere on the board
col8: MX8.1 (COL), MX24.1 (COL), MX43.1 (COL), MX62.1 (COL), MX79.1 (COL); also elsewhere on the board
col9: MX9.1 (COL), MX25.1 (COL), MX44.1 (COL), MX63.1 (COL), MX80.1 (COL), MX94.1 (COL); also elsewhere on the board
col10: MX10.1 (COL), MX26.1 (COL), MX45.1 (COL), MX64.1 (COL), MX81.1 (COL), MX95.1 (COL); also elsewhere on the board
col11: MX11.1 (COL), MX27.1 (COL), MX46.1 (COL), MX65.1 (COL), MX82.1 (COL), MX96.1 (COL); also elsewhere on the board
col12: MX12.1 (COL), MX28.1 (COL), MX47.1 (COL), MX66.1 (COL), MX83.1 (COL), MX97.1 (COL); also elsewhere on the board
col13: MX13.1 (COL), MX29.1 (COL), MX48.1 (COL), MX67.1 (COL), MX84.1 (COL), MX98.1 (COL); also elsewhere on the board
col14: MX14.1 (COL), MX49.1 (COL); also elsewhere on the board
col15: MX15.1 (COL), MX30.1 (COL), MX50.1 (COL), MX68.1 (COL), MX85.1 (COL), MX99.1 (COL); also elsewhere on the board
row0: D7.1 (K), D8.1 (K), D9.1 (K), D10.1 (K), D11.1 (K), D12.1 (K), D13.1 (K), D14.1 (K), D15.1 (K), D16.1 (K), D17.1 (K), D18.1 (K), D19.1 (K), D20.1 (K), D21.1 (K); also elsewhere on the board
row1: D22.1 (K), D23.1 (K), D24.1 (K), D25.1 (K), D26.1 (K), D27.1 (K), D28.1 (K), D29.1 (K), D30.1 (K), D31.1 (K), D32.1 (K), D33.1 (K), D34.1 (K), D35.1 (K), D36.1 (K); also elsewhere on the board
row2: D41.1 (K), D42.1 (K), D43.1 (K), D44.1 (K), D45.1 (K), D46.1 (K), D47.1 (K), D48.1 (K), D49.1 (K), D50.1 (K), D51.1 (K), D52.1 (K), D53.1 (K), D54.1 (K), D55.1 (K), D56.1 (K); also elsewhere on the board
row3: D61.1 (K), D62.1 (K), D63.1 (K), D64.1 (K), D65.1 (K), D66.1 (K), D67.1 (K), D68.1 (K), D69.1 (K), D70.1 (K), D71.1 (K), D72.1 (K), D73.1 (K), D74.1 (K); also elsewhere on the board
row4: D78.1 (K), D79.1 (K), D80.1 (K), D81.1 (K), D82.1 (K), D83.1 (K), D84.1 (K), D85.1 (K), D86.1 (K), D87.1 (K), D88.1 (K), D89.1 (K), D90.1 (K), D91.1 (K); also elsewhere on the board
row5: D96.1 (K), D97.1 (K), D98.1 (K), D99.1 (K), D100.1 (K), D101.1 (K), D102.1 (K), D103.1 (K), D104.1 (K), D105.1 (K); also elsewhere on the board

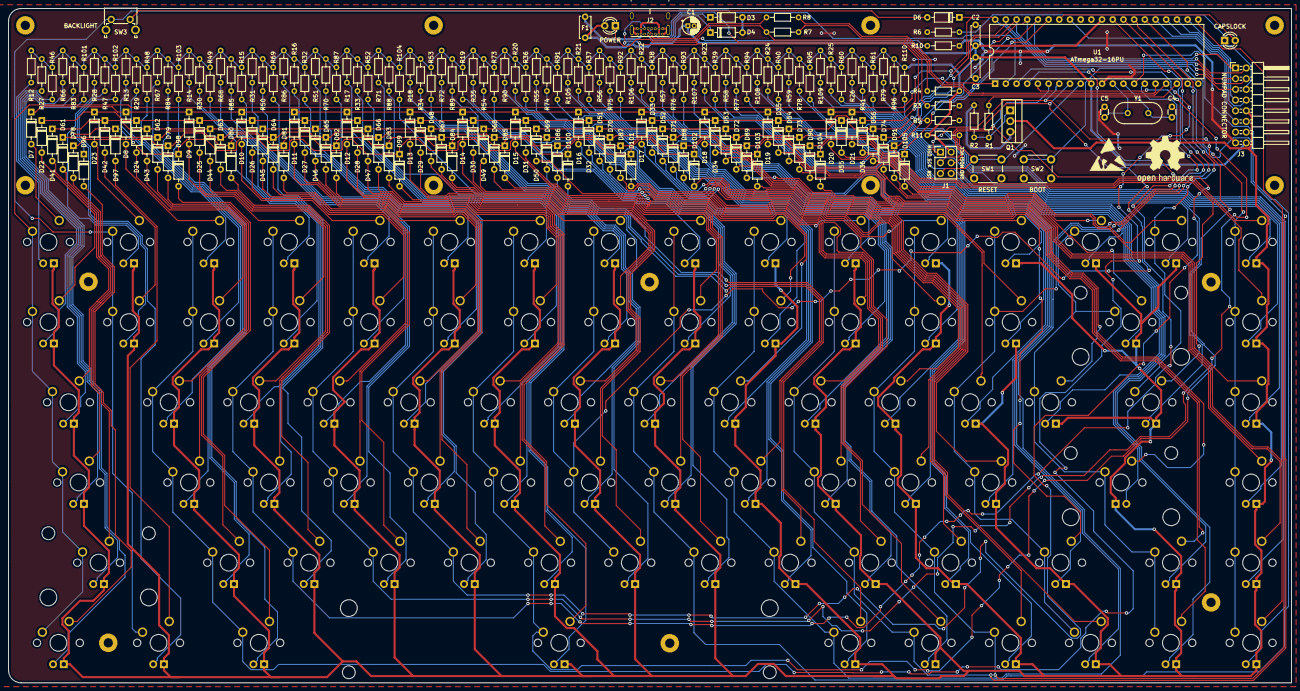
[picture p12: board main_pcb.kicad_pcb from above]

Board: 2 copper layers, 304.8 x 160.2 mm, 296 parts (0 on the bottom side), 215 nets.

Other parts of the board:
MOUNT1, MOUNT2, MOUNT3, MOUNT4, MOUNT5, MOUNT6, MOUNT7, MOUNT8, MOUNT9, MOUNT10, MOUNT11, MOUNT12, MOUNT13, MOUNT14: MountingHole_2.2mm_M2_Pad

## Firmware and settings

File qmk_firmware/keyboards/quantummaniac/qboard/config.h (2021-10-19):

/*
Copyright 2021 QuantumManiac

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
You should have received a copy of the GNU General Public License
along with this program.  If not, see <http://www.gnu.org/licenses/>.
*/

#pragma once

#include "config_common.h"

/* USB Device descriptor parameter */
#define VENDOR_ID    0x1B64
#define PRODUCT_ID   0x9BB3
#define DEVICE_VER   0x0001
#define MANUFACTURER QuantumManiac
#define PRODUCT      QBoard

/* key matrix size */
#define MATRIX_ROWS 6
#define MATRIX_COLS 20

/*
 * Keyboard Matrix Assignments
 *
 * Change this to how you wired your keyboard
 * COLS: AVR pins used for columns, left to right
 * ROWS: AVR pins used for rows, top to bottom
 * DIODE_DIRECTION: COL2ROW = COL = Anode (+), ROW = Cathode (-, marked on diode)
 *                  ROW2COL = ROW = Anode (+), COL = Cathode (-, marked on diode)
 *
 *                        00  01  02  03  04  05  06  07  08  09  10  11  12  13  14  15  16  17  18  19
 */
#define MATRIX_ROW_PINS { A0, A1, A2, A3, A4, A5 }
#define MATRIX_COL_PINS { B0, B1, B2, B3, B4, B5, B6, B7, D0, D1, D5, D7, C7, C6, C5, C4, C3, C2, C1, C0 }
#define UNUSED_PINS

/* COL2ROW, ROW2COL */
#define DIODE_DIRECTION COL2ROW

/*
 * Split Keyboard specific options, make sure you have 'SPLIT_KEYBOARD = yes' in your rules.mk, and define SOFT_SERIAL_PIN.
 */
// #define SOFT_SERIAL_PIN D0  // or D1, D2, D3, E6

#define LED_NUM_LOCK_PIN A7
#define LED_CAPS_LOCK_PIN A6
//#define LED_SCROLL_LOCK_PIN B2
//#define LED_COMPOSE_PIN B3
//#define LED_KANA_PIN B4
#define LED_PIN_ON_STATE 1

#define BACKLIGHT_PIN D4
#define BACKLIGHT_LEVELS 3
// #define BACKLIGHT_BREATHING

//#define RGB_DI_PIN E2
//#ifdef RGB_DI_PIN
//#    define RGBLED_NUM 16
//#    define RGBLIGHT_HUE_STEP 8
//#    define RGBLIGHT_SAT_STEP 8
//#    define RGBLIGHT_VAL_STEP 8
//#    define RGBLIGHT_LIMIT_VAL 255 /* The maximum brightness level */
//#    define RGBLIGHT_SLEEP  /* If defined, the RGB lighting will be switched off when the host goes to sleep */
/*== all animations enable ==*/
//#    define RGBLIGHT_ANIMATIONS
/*== or choose animations ==*/
//#    define RGBLIGHT_EFFECT_BREATHING
//#    define RGBLIGHT_EFFECT_RAINBOW_MOOD
//#    define RGBLIGHT_EFFECT_RAINBOW_SWIRL
//#    define RGBLIGHT_EFFECT_SNAKE
//#    define RGBLIGHT_EFFECT_KNIGHT
//#    define RGBLIGHT_EFFECT_CHRISTMAS
//#    define RGBLIGHT_EFFECT_STATIC_GRADIENT
//#    define RGBLIGHT_EFFECT_RGB_TEST
//#    define RGBLIGHT_EFFECT_ALTERNATING
/*== customize breathing effect ==*/
/*==== (DEFAULT) use fixed table instead of exp() and sin() ====*/
//#    define RGBLIGHT_BREATHE_TABLE_SIZE 256      // 256(default) or 128 or 64
/*==== use exp() and sin() ====*/
//#    define RGBLIGHT_EFFECT_BREATHE_CENTER 1.85  // 1 to 2.7
//#    define RGBLIGHT_EFFECT_BREATHE_MAX    255   // 0 to 255
//#endif

/* Debounce reduces chatter (unintended double-presses) - set 0 if debouncing is not needed */
#define DEBOUNCE 5

/* define if matrix has ghost (lacks anti-ghosting diodes) */
//#define MATRIX_HAS_GHOST

/* Mechanical locking support. Use KC_LCAP, KC_LNUM or KC_LSCR instead in keymap */
#define LOCKING_SUPPORT_ENABLE
/* Locking resynchronize hack */
#define LOCKING_RESYNC_ENABLE

/* If defined, GRAVE_ESC will always act as ESC when CTRL is held.
 * This is useful for the Windows task manager shortcut (ctrl+shift+esc).
 */
//#define GRAVE_ESC_CTRL_OVERRIDE

/*
 * Force NKRO
 *
 * Force NKRO (nKey Rollover) to be enabled by default, regardless of the saved
 * state in the bootmagic EEPROM settings. (Note that NKRO must be enabled in the
 * makefile for this to work.)
 *
 * If forced on, NKRO can be disabled via magic key (default = LShift+RShift+N)
 * until the next keyboard reset.
 *
 * NKRO may prevent your keystrokes from being detected in the BIOS, but it is
 * fully operational during normal computer usage.
 *
 * For a less heavy-handed approach, enable NKRO via magic key (LShift+RShift+N)
 * or via bootmagic (hold SPACE+N while plugging in the keyboard). Once set by
 * bootmagic, NKRO mode will always be enabled until it is toggled again during a
 * power-up.
 *
 */
//#define FORCE_NKRO

/*
 * Feature disable options
 *  These options are also useful to firmware size reduction.
 */

/* disable debug print */
//#define NO_DEBUG

/* disable print */
//#define NO_PRINT

/* disable action features */
//#define NO_ACTION_LAYER
//#define NO_ACTION_TAPPING
//#define NO_ACTION_ONESHOT

/* disable these deprecated features by default */
#define NO_ACTION_MACRO
#define NO_ACTION_FUNCTION

/* Bootmagic Lite key configuration */
//#define BOOTMAGIC_LITE_ROW 0
//#define BOOTMAGIC_LITE_COLUMN 0

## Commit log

2021-08-25 Initial directory setup
    [main_pcb.kicad_pcb, main_pcb.sch]
2021-08-26 Finish initial schematics
    [keys.sch, main_pcb.sch, numpad_pcb.kicad_pcb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]
2021-08-26 Cleanup schematics and generate PDFs
    [keys.sch, main_pcb.sch, numpad_pcb.sch]
2021-08-27 Revise schematics to not have detachable numpad
    [keys.sch, main_pcb.kicad_pcb, main_pcb.sch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]
2021-08-27 Finish footprint assignments
    [keys.sch, main_pcb.kicad_pcb, main_pcb.sch]
2021-08-27 Begin PCB Layout
    [main_pcb.kicad_pcb]
2021-08-27 Begin revised PCB layout
    [keys.sch, main_pcb.kicad_pcb, main_pcb.sch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]
2021-08-28 Finish rough Resistor and Diode layout
    [main_pcb.kicad_pcb]
2021-08-28 Fix mismatched pin
2021-08-28 Continue PCB Layout
    [main_pcb.kicad_pcb]
2021-08-28 Added copper planes
    [main_pcb.kicad_pcb]
2021-08-28 removed some silk screens, added some, moved stuff around
    [main_pcb.kicad_pcb]
2021-08-28 adjusted edge cuts to be square
    [main_pcb.kicad_pcb]
2021-08-28 moved capacitors
    [main_pcb.kicad_pcb]
2021-08-28 moved holes
    [main_pcb.kicad_pcb]
2021-08-28 flushed connector, centered
    [main_pcb.kicad_pcb]
2021-08-28 Finish layout for numpad PCB
    [numpad_pcb.kicad_pcb]
2021-08-28 Fix mounting hole
    [numpad_pcb.kicad_pcb]
2021-08-28 Move silkscreen for numpad
    [numpad_pcb.kicad_pcb]
2021-08-28 reordered diodes to allow for easier traces
    [main_pcb.kicad_pcb]
2021-08-28 began traces on main board
    [main_pcb.kicad_pcb]
2021-08-28 Finish numpad routing
    [numpad_pcb.kicad_pcb]
2021-08-29 Rearrange main board diodes
    [main_pcb.kicad_pcb, numpad_pcb.kicad_pcb]
2021-08-30 Finish routing main PCB
    [main_pcb.kicad_pcb, numpad_pcb.kicad_pcb]
2021-08-30 Freerouting work
    [main_pcb.dsn, main_pcb.kicad_pcb, numpad_pcb.dsn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]
2021-08-30 Revert freerouting
    [main_pcb.dsn, main_pcb.kicad_pcb, numpad_pcb.dsn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]
2021-08-30 Finish PCB Silkscreen Decor
    [main_pcb.kicad_pcb, numpad_pcb.kicad_pcb]
2021-09-05 Fix wrong pinout on MOSFET
    [main_pcb.kicad_pcb, main_pcb.sch]
2021-09-07 Fix USB footprint
    [main_pcb.kicad_pcb]
2021-09-07 Fix pin issue in schematic and netlist
    [main_pcb.kicad_pcb, main_pcb.sch]
2021-09-09 Finish final PCB checks
    [main_pcb.kicad_pcb]
2021-09-10 Generate gerbers and update schematics
    [main_pcb-B_Cu.gbl, main_pcb-B_Cu.gbr, main_pcb-B_Mask.gbr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]
2021-09-10 Update gerbers
    [main_pcb-B_Cu.gbl, main_pcb-B_Cu.gbr, main_pcb-B_Mask.gbr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]
2021-09-18 Regenerate backplate files as dxf
    [main_pcb-Edge_Cuts.dxf, main_pcb-F_Cu.dxf, numpad_pcb-Edge_Cuts.dxf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]
2021-09-18 Remove acrylic files
    [main_pcb-Edge_Cuts.dxf, main_pcb-F_Cu.dxf, numpad_pcb-Edge_Cuts.dxf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]
2021-09-18 Finish dwg for main board backplate
    [numpad_backplate.dwg]
2021-09-18 numpad backplate/frontplate
    [Numpad.dwg]
2021-09-18 rename files
    [Numpad.dwg, main_backplate.dwg, numpad_backplate.dwg]
2021-09-18 added front plate to main, renamed files
    [main_backplate.dwg, main_plate.dwg, numpad_plate.dwg]
2021-09-18 moved 1 mm up bottom line
    [main_plate.dwg, numpad_plate.dwg]
2021-09-18 Add acrylic cut files
    [_cover_acrylic_clear.dwg, _plate_acrylic_black.dwg, main_plate.dwg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]
2021-09-27 fixed eps issue, exported
    [_cover_acrylic_clear.dwg, _plate_acrylic_black.dwg]
2021-10-31 Cleanup and documenting
    [_cover_acrylic_clear.dwg, _cover_acrylic_clear.dxf, _plate_acrylic_black.dwg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]

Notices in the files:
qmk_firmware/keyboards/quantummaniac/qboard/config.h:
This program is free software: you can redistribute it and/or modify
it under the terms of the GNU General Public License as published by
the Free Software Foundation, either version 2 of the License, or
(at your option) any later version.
